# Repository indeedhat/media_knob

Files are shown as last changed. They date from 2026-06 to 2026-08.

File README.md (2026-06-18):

# Media Knob
A little HID device to control media and scrolling.

Tested on linux, macos and windows

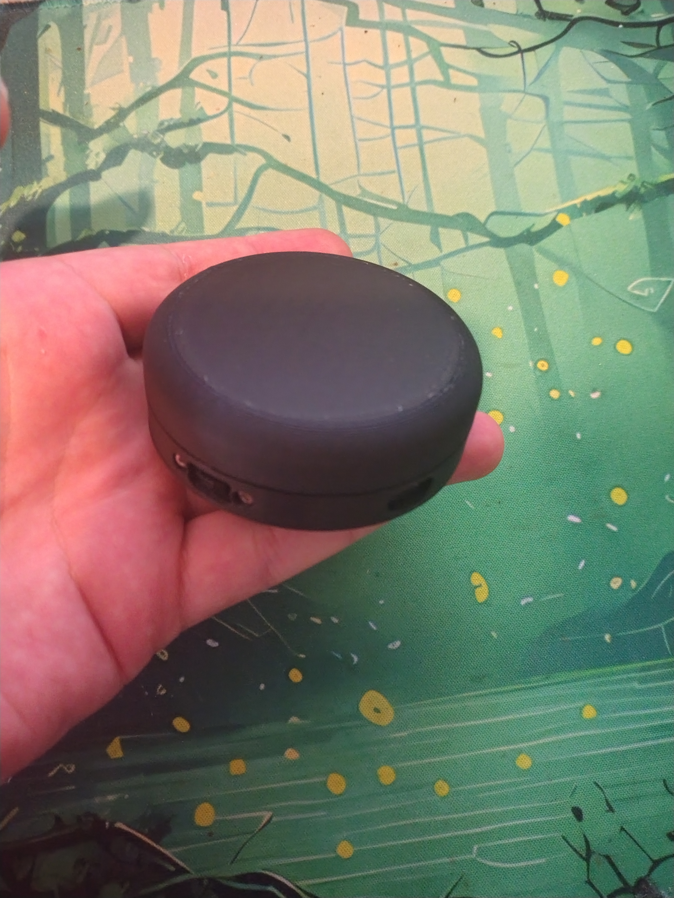
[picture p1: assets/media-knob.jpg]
media knob


## Build Guide
[Build Guide found heer](build-guide.md)

## Controls
The device has 3 inputs:
- Spin dial
- Side button (mode switch)
- Button in base under the foot opposite the USB port (Mod)

### Scroll mode

| Direction | Mod | Action |
| --- | --- | --- |
| Clockwise | No | Scroll Up |
| Counter Clockwise | No | Scroll Down |
| Clockwise | Yes | Zoom in |
| Counter Clockwise | Yes | Zoom out |

### Media Mode

| Direction | Mod | Action |
| --- | --- | --- |
| Clockwise | No | Volume Up |
| Counter Clockwise | No | Volume Down |
| Clockwise | Yes | Next track |
| Counter Clockwise | Yes | Previous track |
| N/A | Double Tap | Play/Pause |

## Bluetooth Operation
- The device shows up as "Knoblet".
- It will allow up to 5 devices to be paired but only one device to be connected at a time.
- pairing to a 6th device will remove the oldest pairing
- when pairing to a device that it already has a pairing for but the key has changed (for example if you remove the device from your pc and then re add it) connection will fail the first time and the pairing will be cleared for that device. The secrond time you try connect it will pair correctly. This is intended functionality to remove the need for a dedicated clear pairing button.

## OS Support
- Linux: works as intended out of the box
    - I do not know if all distros support high res scrolling but so far it has worked on all the distro's i have tried
- Windows: works as intended out of the box
- MacOS: does not natively support high res scrolling, I have had the best results using [Better Mouse](https://better-mouse.com/)

## Battery life
I have not been tracking this as well as I could have but I would estimate about 16 hours usage between charges with the 110mah battery I am using.
It is on my roadmap to implement some battery saving features but I haven't found time to prioritise them as of yet.

## Roadmap
### Software
- [x] scroll mode
    - [x] high res scrolling
    - [x] zoom
- [x] media media
    - [x] play/pause
    - [x] volume
    - [x] next/prev
- [x] mode switching (scroll/media)
- [ ] bluetooth
    - [x] Connect via bluetooth
    - [ ] low power mode
        - in progress
    - [x] properly report battery life
- [ ] usb
    - [x] get usb working alone
    - [ ] get usb working along side bluetooth

### Hardware
- [x] connect as5600 sensor
- [x] trigger a button when you press on the dial
- [x] mode switching button
- [x] sort out battery

### Cad
- [x] dial
- [x] bottom cover
- [x] main body (needs updating for buttons)

### Other
- [x] create build guide
    - needs updating
- [x] upload STL files for 3d printing

## Possible tasks
It might be nice to have a macro mode that lets you configure what the dial does in an application
running on the host device.

## Wiring
### as5600
- scl -> 011 - yellow
- sda -> 100 - green

### input
- mode -> 111 - blue
- mod  -> 010 - white

## Credits
The idea comes from [This Video](https://www.youtube.com/watch?v=FSy9G6bNuKA&t=287s) by
[Engineer Bo](https://www.youtube.com/@engineerbo) with some extra features of my own.  
Without that video a would never have had the idea to create a project like this on my own and
wouldn't even know that High res scrolling was a thing
There is absolutely no doubt in my mind that his version is significantly higher quality and more refined
than this project, this is more aimed for people that like to build things themselves.

The project is built on top of [Zephyr Project](https://www.zephyrproject.org/).

I spent a good amount of time reading through the bluetooth logic from [ZMK](https://zmk.dev/) to
get my bluetooth working, I don't recall directly copying any of their code but its likely to be
pretty damn similar in a lot of ways.

[Claude.ai](https://claude.ai) was my Clanker of choice for troubleshooting and helping with research
but was not used for code generation. It was of questionable usefulness throughout the project and
I am sceptical of if it actually saved me any time but I did make use of it to some degree and I
think that its important to recognise its usage.

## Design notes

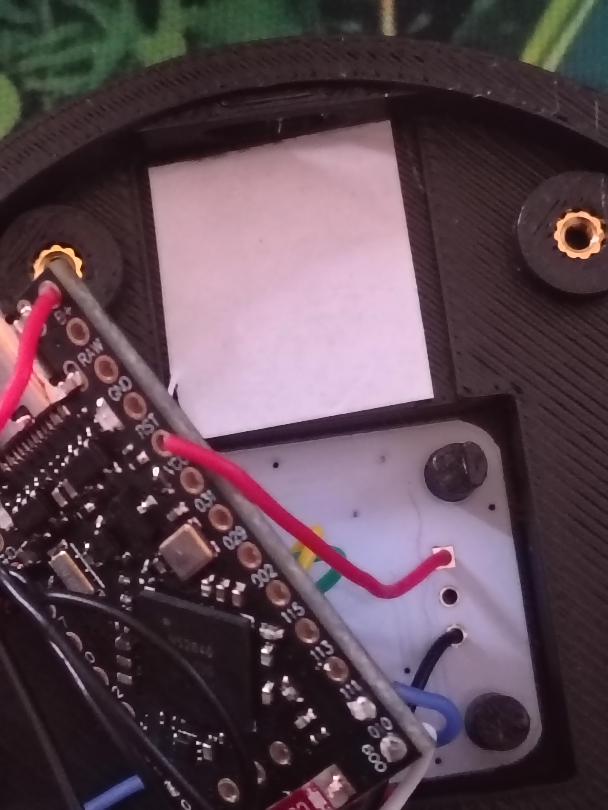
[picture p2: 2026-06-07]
assets/pro-micro-tape.jpg

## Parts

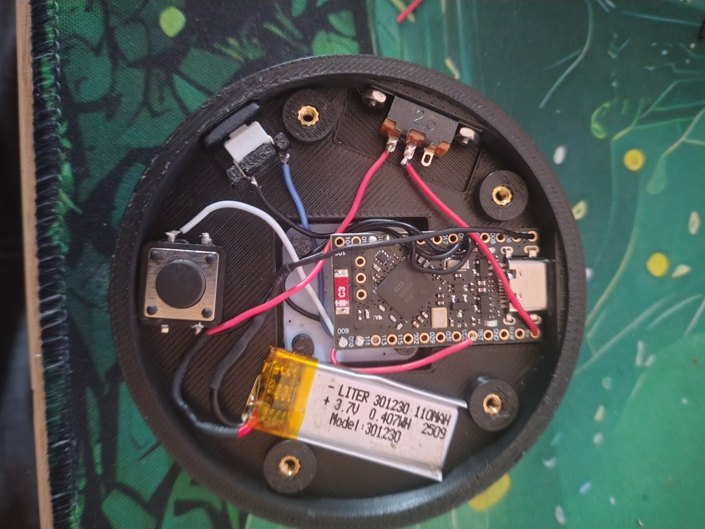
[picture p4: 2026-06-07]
assets/final-parts-in.jpg

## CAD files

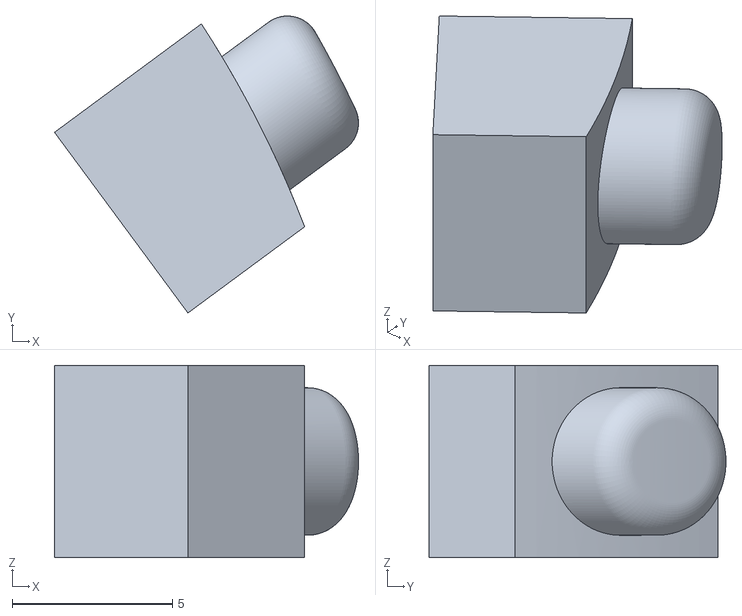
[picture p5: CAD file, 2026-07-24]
cad/side-button-2.stl
9.48 x 9.26 x 6.00

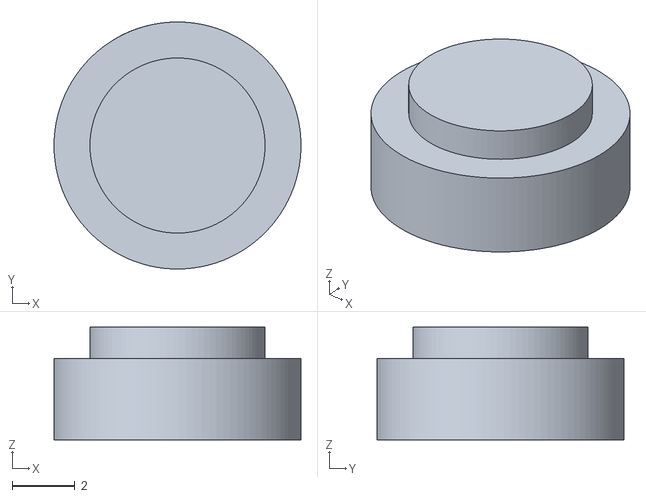
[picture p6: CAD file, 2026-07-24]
cad/mod-button.stl
7.90 x 7.90 x 3.60

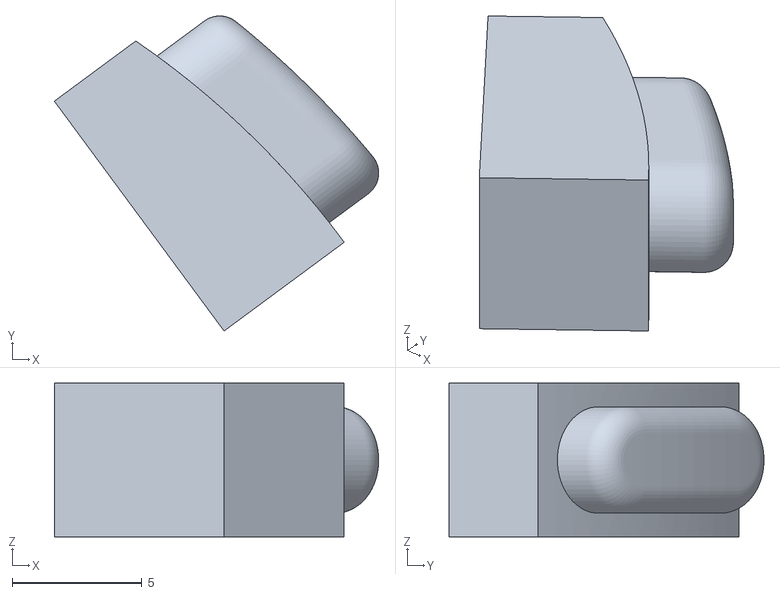
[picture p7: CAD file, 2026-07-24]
cad/side-button-1.stl
12.5 x 12.1 x 5.92

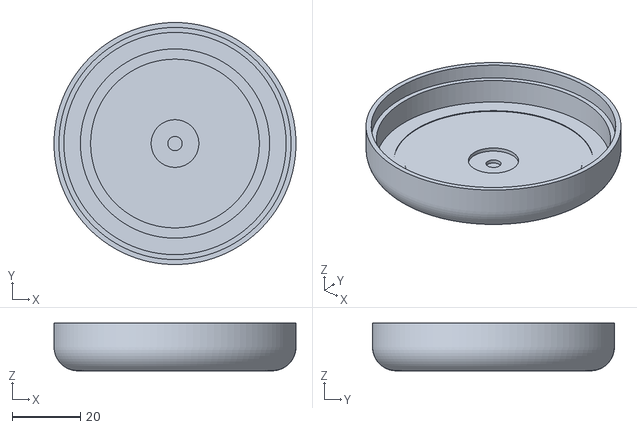
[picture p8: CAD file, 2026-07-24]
cad/dial.stl
71.0 x 71.0 x 14.0

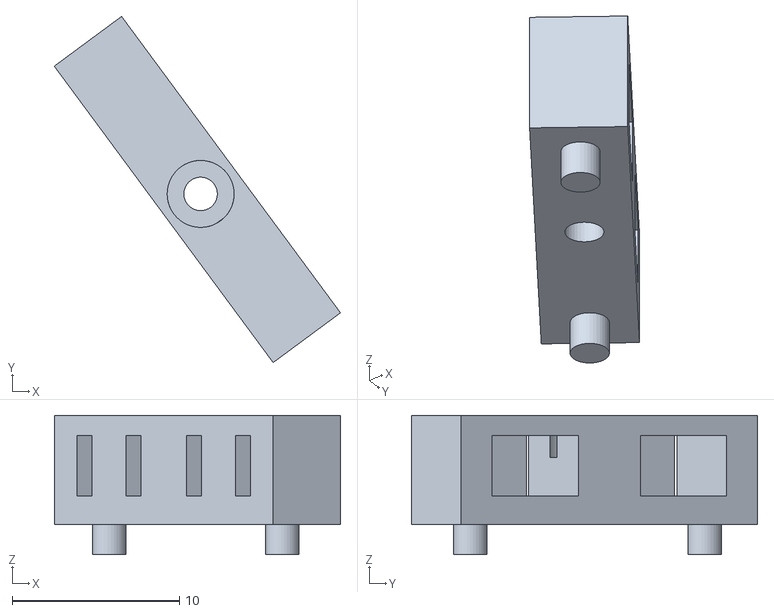
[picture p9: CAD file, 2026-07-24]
cad/side-button-cage.stl
17.1 x 20.7 x 8.30

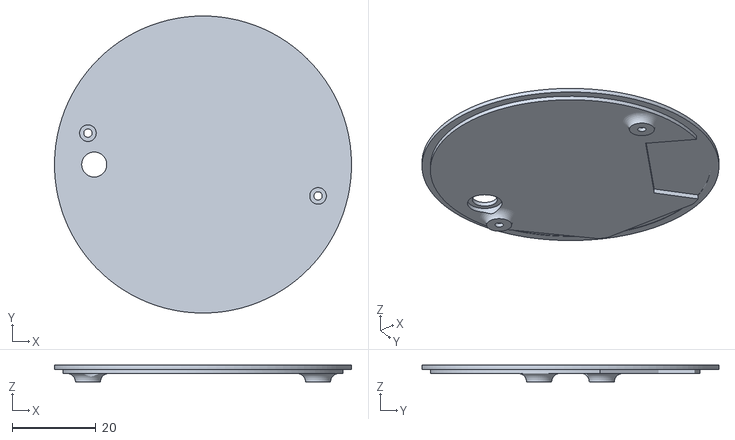
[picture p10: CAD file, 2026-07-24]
cad/bottom-cover.stl
71.0 x 71.0 x 4.00

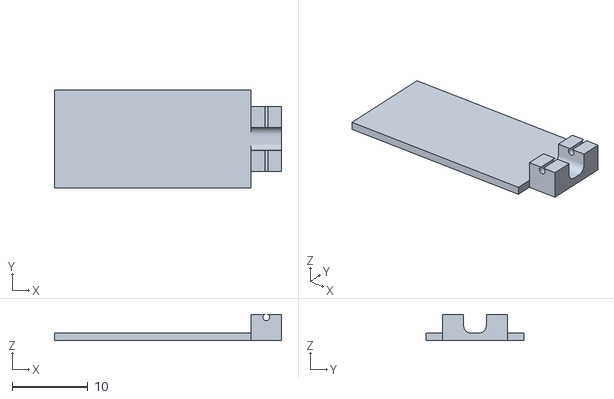
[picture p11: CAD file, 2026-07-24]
cad/controller-sledge.stl
30.0 x 13.0 x 3.50

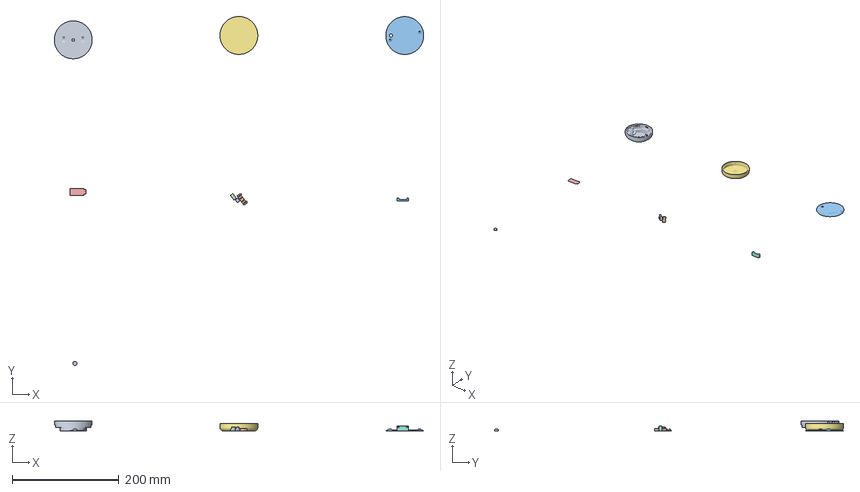
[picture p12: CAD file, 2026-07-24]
cad/knoblet-v2.3mf
692.1 x 653.8 x 18.9 mm
body.stl
side-button-cage.stl
bottom-cover.stl
side-button-1.stl
controller-sledge.stl
side-button-2.stl
dial.stl
usb-bracket.stl
mod-button.stl

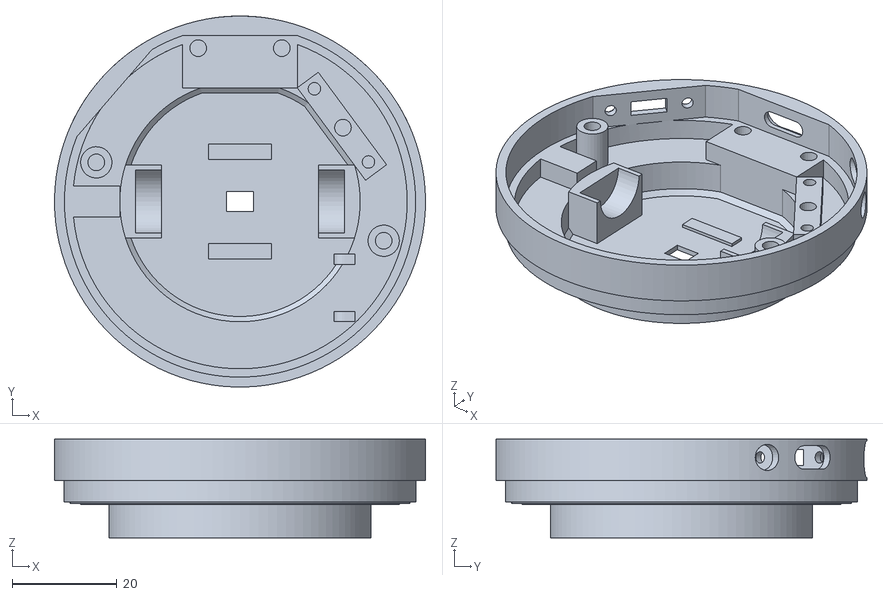
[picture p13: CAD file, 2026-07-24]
cad/body.stl
71.0 x 71.0 x 18.9

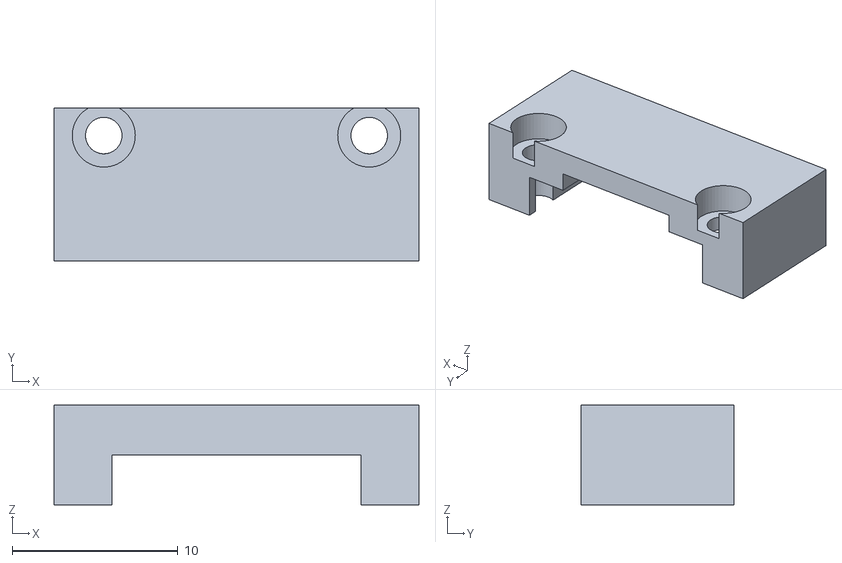
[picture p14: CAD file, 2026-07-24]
cad/usb-bracket.stl
22.0 x 9.20 x 6.00

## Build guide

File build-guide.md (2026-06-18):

## Parts list

> [!NOTE]
> This build guide is a little out of date, the base has been rearranged and there is now a button in the bottom cover
> for the mod button, It should still be close enough to manage the build but i will update this soon with new pictures
> and updated instructions

### Electrical
- 1x [Pro micro nrf52840 micro controller](https://www.aliexpress.com/w/wholesale-Nrf52840-Pro-Micro.html?spm=a2g0o.detail.search.0)
- 1x [as5600 magnetic encoder (white dev board)](https://www.aliexpress.com/w/wholesale-as5600.html?spm=a2g0o.productlist.search.0)
- 1x [301230 lipo battery](https://www.aliexpress.com/w/wholesale-301230.html?spm=a2g0o.productlist.search.0)
- 1x 6x6x4.3 push button
- 1x 12x12x5 patch push button
- 1x SS12D10 2 position toggle switch

### Hardware
- 4x m2x4x3.2 heat set inserts
- 6x m2x4 bolts
- 2x m2 nuts

### Printed Parts
- 1x [Dial Base](cad/base.stl)
- 1x [Base Cover](cad/bottom-cover.stl)
- 1x [Dial Top](cad/dial.stl)
- 1x [Mode Switch Button](cad/mode-button.stl)

### Other
- 1x [65mm od x 50mm x 7mm bearing ](https://www.aliexpress.com/item/1005011831553272.html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{%22order%22%3A%2214%22%2C%22eval%22%3A%221%22%2C%22fromPage%22%3A%22search%22}&pdp_npi=6%40dis!GBP!13.41!6.71!!!118.46!59.23!%40211b655217808439447296990e0848!12000056729960207!sea!UK!2482384161!X!1!0!n_tag%3A-29919%3Bd%3Acda67a48%3Bm03_new_user%3A-29895&curPageLogUid=0vgzU3UKqwhK&utparam-url=scene%3Asearch|query_from%3A|x_object_id%3A1005011831553272|_p_origin_prod%3A)
- 5x rubber feet (whatever size you want)
- thing gage wire
- heat shrink (optional but recommended)
- double sided tape

### Tools
- Soldering Iron
- driver for m2 bolts
- wire cutters
- wire strippers
- 3d printer

## Build instructions
1) Insert the bearing into the dial top. This should fit snugly without any need for adhesive.
2) Insert the magnet provided with your as5600 into the center cavity of the dial top. This should fit snugly but a little adhesive is probably a good idea.
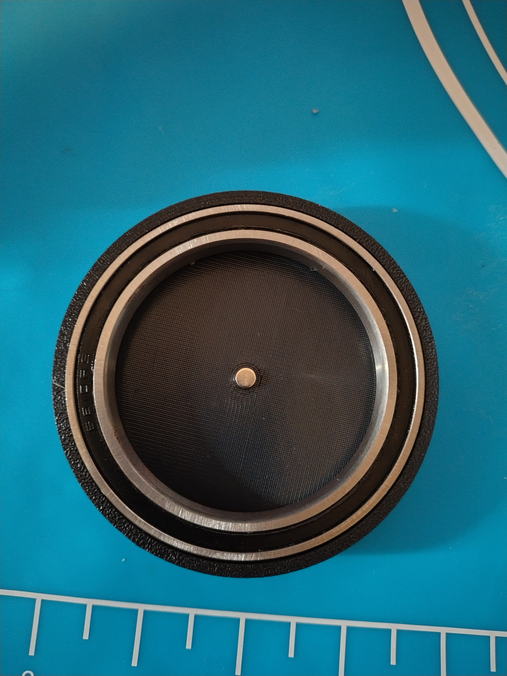
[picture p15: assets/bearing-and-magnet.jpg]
bearing and magnet


3) Use a soldering iron to insert the m2 heated inserts into their holes
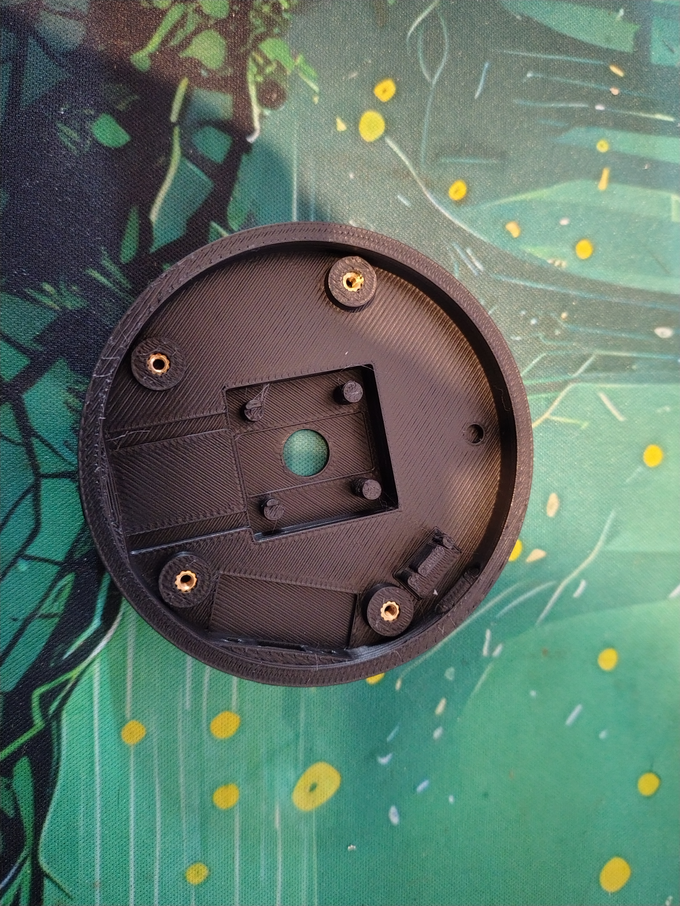
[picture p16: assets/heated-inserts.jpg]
heated inserts


4) solder wires to the GND, VCC, SCL and SDA pins of the as5600 with the wires trailing out through the back
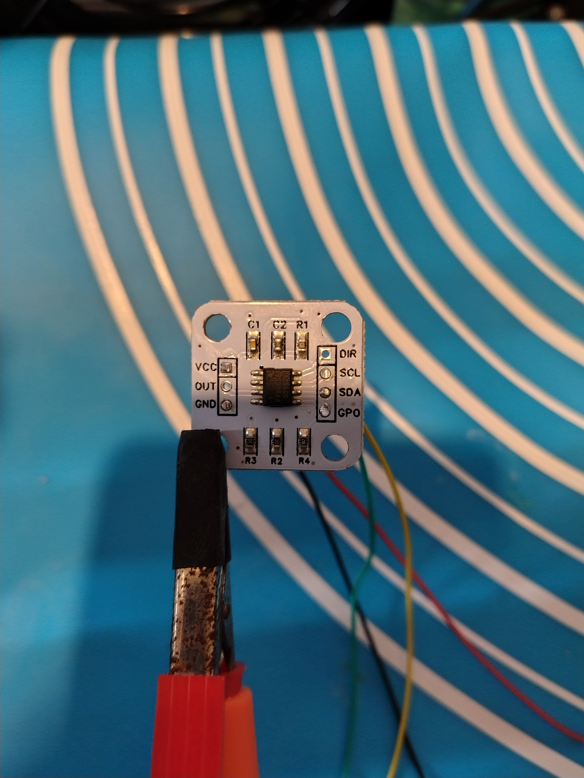
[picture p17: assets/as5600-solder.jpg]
as5600 wires


5) Insert the as5600 into its recess. All of my boards have the sensor slightly offset and the print has been adjusted to account for this, you need the 4 hole side aligned with the power switch cutout to properly align the sensor.
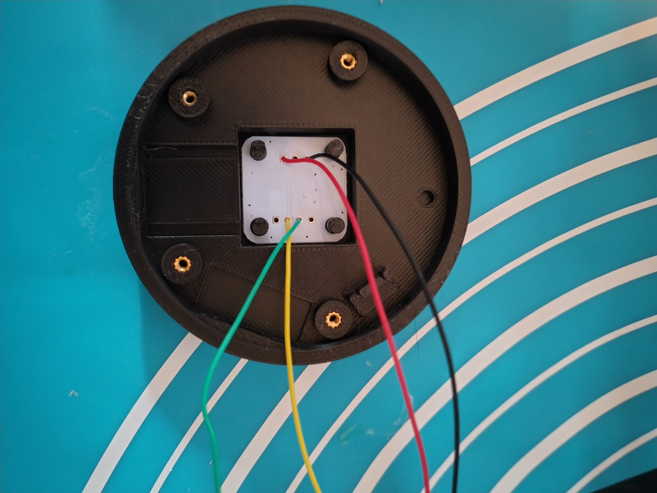
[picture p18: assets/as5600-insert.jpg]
as5600 insert


6) Insert the Mode switch button into its cutout and secure with the 6x6x4.3 push button.
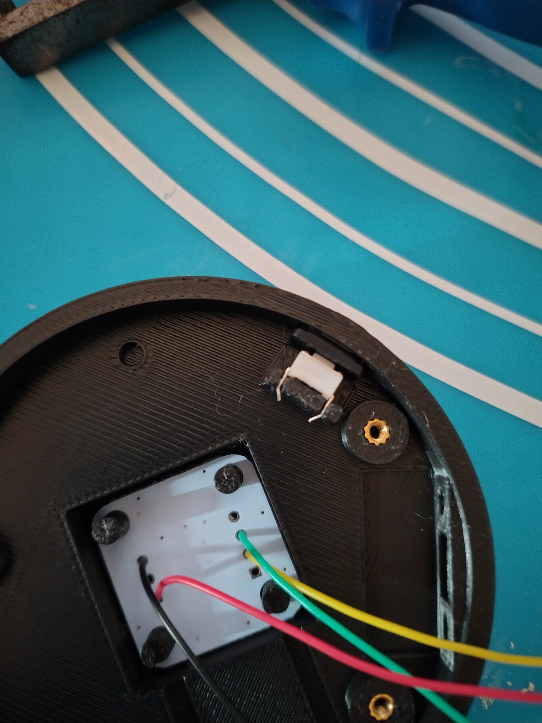
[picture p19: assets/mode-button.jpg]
mode button


7) Solder 2 wires to the power button then screw it into place. You can solder the wires after insertion but doing them first is much simpler
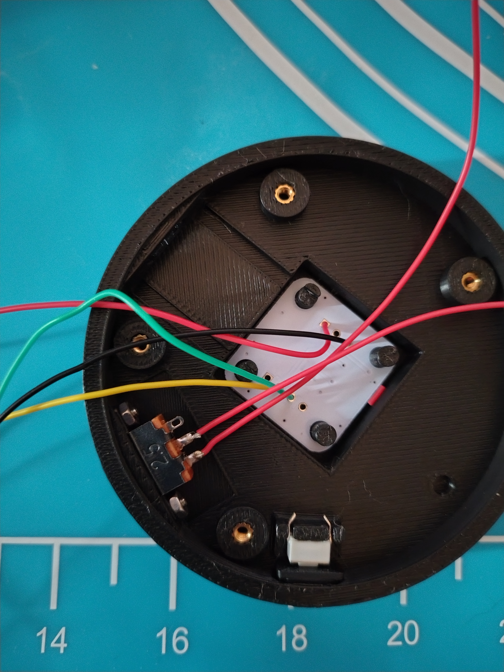
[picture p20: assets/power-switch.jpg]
power switch


8) Solder a data and ground wire to the mode switch button
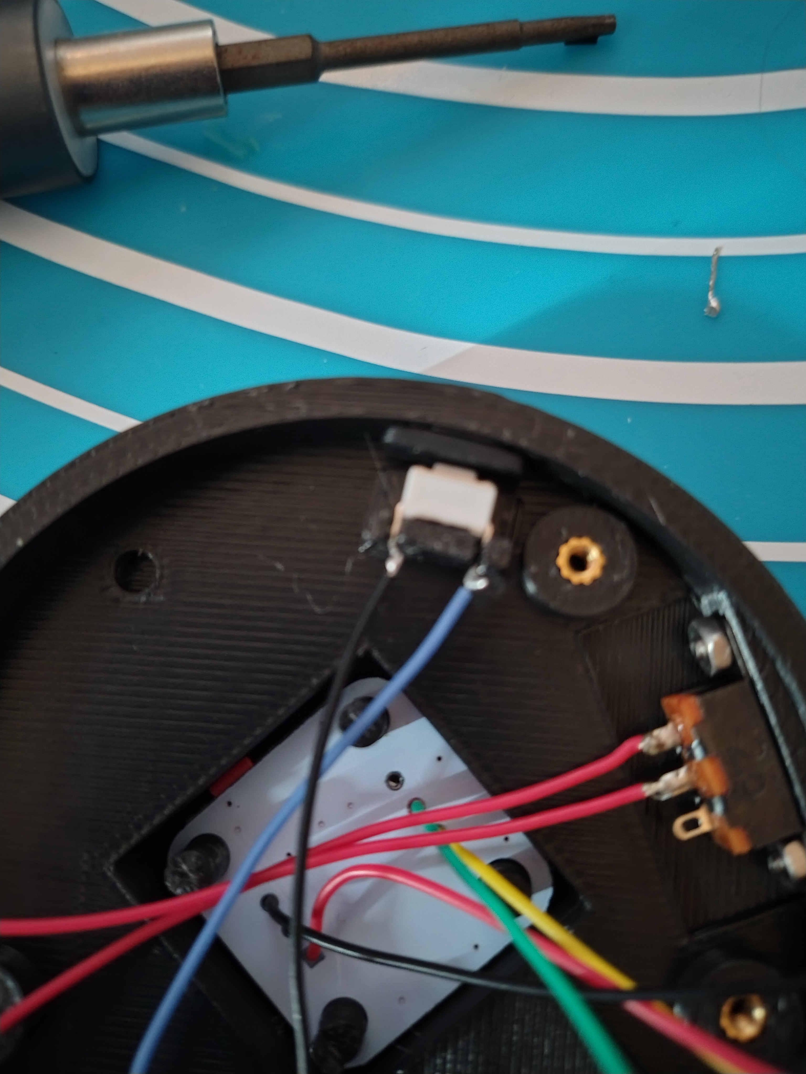
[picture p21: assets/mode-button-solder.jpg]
mode button solder


9) Solder a ground and data wire to the 12x12x5 push button and use a small amount of double sided tape to secure it in place.  
    __Note: here that in the image I have soldered the wires in the wrong location, they should be diagonal from each other.__
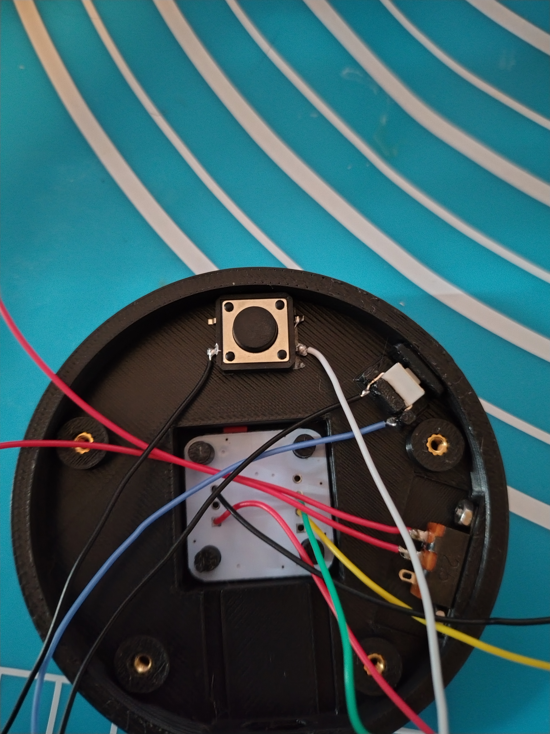
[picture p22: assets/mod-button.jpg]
mod button


10) Cut all your wires to a more reasonable length and solder everything to the micro controller.

| component | wire | pin |
| --- | --- | --- |
| as5600 | GND (black) | GND |
| as5600 | VCC (red) | VCC |
| as5600 | SCL (yellow) | 011 |
| as5600 | SDA (green) | 100 |
| Mode Sw | black | GND |
| Mode Sw | blue | 111 |
| Mod Sw | black | GND |
| Mod Sw | white | 010 |
| Power Sw | red | B+ |
| N/A | black | B- |

11) Stick the micro controller in place with some double sided tape.  
    __Note: the cheap controllers don't all have the usb port at the same height relative to the board. I have setup the model to account for the most offset board i have and so you may need to pad the bottom of the board to make it line up propperly__
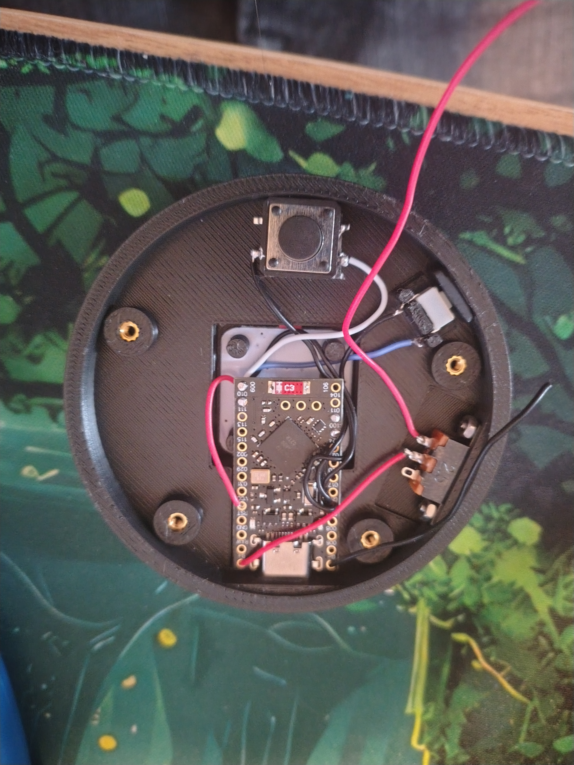
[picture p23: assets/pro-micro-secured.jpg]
pro micro secured


12) Wire up the battery to the remaining power switch wire and black wire coming out of B-. I recommend using either some heat shrink if you have it or electrical tape to wrap the wires and prevent shorts.
13) Stick the battery in place with some double sided tape.
parts in place

14) push the dial top into place over its peg. This should fit snugly with no need  for adhesive.

15) flash the controller:
    - Connect the pro micro to a computer via usb
    - quickly short the rst pin to gnd twice
    - the red light should slowly pulse and an external storage device will show up on your computer
    - copy the latest uf2 file from the releases page to your controller.
    - once coppied the device will automatically eject from your computer and restart.

16) screw the base plate into place.  
    Don't put too much screw pressure on the two bolts either side of the mod button or it will stay permanently pressed.

17) turn on the power switch and connect the device to start using it.

## Note on charging
To actually charge the device the power switch needs to be in the on position or there will be no connection to the battery.

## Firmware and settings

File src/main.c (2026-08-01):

#include <zephyr/sys/printk.h>
#include <zephyr/device.h>
#include <zephyr/drivers/regulator.h>
#include <zephyr/input/input.h>
#include <zephyr/settings/settings.h>
#include <zephyr/drivers/gpio.h>
#include <zephyr/kernel.h>

#include "main.h"
#include "hid.h"
#include "bt.h"
#include "as5600.h"
#include "battery.h"
#include "zephyr/init.h"
#include "zephyr/logging/log.h"


static void scroll_action(int16_t angle);
static void media_action(int16_t angle);
#if defined CONFIG_KNOBLET_ENABLE_MACRO_MODE
static void macro_action(int8_t button_idx, int8_t button_state, int16_t angle);
#endif
static void button_input_cb(struct input_event *evt, void *user_data);
static void trigger_media_event(uint16_t media_event);
static void init_settings();
static void submit_report(const char *trigger_name, const uint16_t size, const uint8_t *const report);


int current_mode = MODE_SCROLL;
int mod_btn_pressed = 0;

int64_t last_seek_time = 0;
int64_t last_mod_up_time = 0;


devices device_state = {
	.as5600 = DEVICE_DT_GET_ANY(ams_as5600),
};

static const struct gpio_dt_spec vcc_enable = {
    .port = DEVICE_DT_GET(DT_NODELABEL(gpio0)),
    .pin = 13,
    .dt_flags = GPIO_ACTIVE_HIGH,
};


LOG_MODULE_REGISTER(main, LOG_LEVEL_DBG);
INPUT_CALLBACK_DEFINE(NULL, button_input_cb, NULL);


SYS_INIT(bt_init, APPLICATION, 1);


int main(void)
{
	int err;

	gpio_pin_configure_dt(&vcc_enable, GPIO_OUTPUT_ACTIVE);

#if defined CONFIG_KNOBLET_SAVE_MODE_STATE
	init_settings();
#endif

	err = init_battery_level();
	if (err) {
		LOG_ERR("Failed to init battery report loop");
	}

	err = as5600_init(device_state.as5600);
	if (err != 0) {
		return err;
	}

	while (true) {
		if (as5600_jitter_compensation_enabled()) {
			k_msleep(AS5600_JITTER_DELAY_MS);
		} else {
			k_msleep(current_mode == MODE_SCROLL ? SCROLL_POLL_DELAY : MEDIA_POLL_DELAY);
		}

		int16_t angle = as5600_read(device_state.as5600);

		switch (current_mode) {
		case MODE_SCROLL:
			scroll_action(angle);
			break;
		case MODE_MEDIA:
			media_action(angle);
			break;
#if defined CONFIG_KNOBLET_ENABLE_MACRO_MODE
		case MODE_MACRO:
			macro_action(0, 0, angle);
			break;
#endif
		};
	}

	return 0;
}


static void init_settings()
{
	int size = settings_load_one(SETTINGS_MODE, &current_mode, sizeof(current_mode));
	current_mode %= MODE_COUNT;

	if (size < 0) {
		LOG_ERR("failed to load mode from settings");
	}
}


/**
 * @brief scroll_action handles sending an angle event to the host when in scroll mode
 *
 * @param[in] angle the angle of change
 */
static void scroll_action(int16_t angle)
{
	if (angle == 0) {
		return;
	}

	uint8_t report[MOUSE_REPORT_SIZE] = {0};
	report[MOUSE_REPORT_IDX] = MOUSE_REPORT_ID;
	report[MOUSE_ANGLE_IDX] = angle;

	submit_report("hid scroll", MOUSE_REPORT_SIZE, report);
}


/**
 * @brief media_action handles sending an angle event to the host when in media mode
 *
 * @param[in] angle the angle of change
 */
static void media_action(int16_t angle)
{
	uint8_t report[MEDIA_REPORT_SIZE];
	report[MEDIA_REPORT_IDX] = MEDIA_REPORT_ID;
	
	if (angle == 0) {
		return;
	}

	// After we skip the track we want to debounce for a short period so we
	// don't accidentally skip multiple tracks or change the volume as we
	// release the press.
	// The debounce time is purely set based on when the skip happens.
	int64_t now = k_uptime_get();
	if (now < last_seek_time + MEDIA_DEBOUNCE_TIME) {
		if (mod_btn_pressed) {
			last_seek_time = now;
		}
		return;
	}

	if (mod_btn_pressed) {
		last_seek_time = now;

		trigger_media_event(angle > 0
			? HID_MEDIA_SCAN_NEXT
			: HID_MEDIA_SCAN_PREV
		);
		return;
	}

	trigger_media_event(angle > 0
		? HID_MEDIA_VOL_UP
		: HID_MEDIA_VOL_DONW
	);
}


#if defined CONFIG_KNOBLET_ENABLE_MACRO_MODE
/**
 * @brief macro_action handles sending all input to the desktop application when in macro mode
 *
 * @param[in] button_idx the current button being pressed/released (0 = no button)
 * @param[in] button_state the current state of the button in question
 * @param[in] angle the angle of change
 */
static void macro_action(int8_t button_idx, int8_t button_state, int16_t angle)
{
	if (angle == 0 && button_idx == 0) {
		return;
	}

	uint8_t report[MACRO_REPORT_SIZE];
	report[MACRO_REPORT_IDX] = MACRO_REPORT_ID;
	report[MACRO_KEY_IDX] = button_idx;
	report[MACRO_KEY_STATE_IDX] = button_state;
	report[MACRO_ANGLE_HIGH_IDX] = angle >> 8;
	report[MACRO_ANGLE_LOW_IDX] = angle & 0xFF;


	LOG_INF("macro angle %d", angle);
	submit_report("macro", MACRO_REPORT_SIZE, report);
}
#endif


/**
 * @brief button_input_cb hadles button presses when the evnt is sent from the zephyr
 *        input subsystem
 *
 * @param[in] evt the input event
 * @param[in] user_data the user data for the event
 */
static void button_input_cb(struct input_event *evt, void *user_data)
{
	LOG_INF("button pressed %d", evt->code);

	if (evt->sync == 0) {
		return;
	}

	if (evt->code == BTN_MODE_CODE) {
		if (evt->value != 0) {
			return;
		}

		current_mode = (current_mode + 1) % MODE_COUNT;

	#if defined CONFIG_KNOBLET_SAVE_MODE_STATE
		int err = settings_save_one(SETTINGS_MODE, &current_mode, sizeof(current_mode));
		if (err != 0) {
			LOG_ERR("Failed to save mode to settings");
		}
	#endif

		LOG_INF("Set mode to %s", current_mode == MODE_SCROLL ? "scroll" : "media");
		return;
	}

	if (evt->code != BTN_MOD_CODE && evt->code != BTN_MOD2_CODE) {
		return;
	}

	mod_btn_pressed = evt->value;
	switch (current_mode) {
	case MODE_MEDIA:
		if (evt->value) {
			return;
		}

		int64_t now = k_uptime_get();
		if (last_mod_up_time + MEDIA_DOUBLE_TAP_INTERVAL > now) {
			last_mod_up_time = 0;

			trigger_media_event(HID_MEDIA_PLAY_PAUSE);
			return;
		}

		last_mod_up_time = now;
		break;

	case MODE_SCROLL:
		uint8_t report[KEEB_REPORT_SIZE] = {0};
		report[KEEB_REPORT_IDX] = KEEB_REPORT_ID;
		report[KEEB_MODIFIER_IDX] = evt->value
			? HID_KBD_MODIFIER_LEFT_CTRL
			: HID_KBD_MODIFIER_NONE;

		submit_report("hid keeyboard",KEEB_REPORT_SIZE, report);
		break;

#if defined CONFIG_KNOBLET_ENABLE_MACRO_MODE
	case MODE_MACRO:
		macro_action(evt->code, evt->value, 0);
		break;
#endif
	}
}


/**
 * @brief submit_report submits a HID report to the host via the bluetooth subsystem
 *
 * @param[in] trigger_name display name for the log
 * @param[in] size the report size
 * @param[in] report the report data
 */
static void submit_report(
	const char *trigger_name,
	const uint16_t size,
	const uint8_t *const report
) {
	if (!bt_connected()) {
		return;
	}

	int err = bt_submit_report(size, report);
	if (err) {
		LOG_ERR("failed to send %s event: %d", trigger_name, err);
		return;
	}

	LOG_DBG("%s event sent", trigger_name);
}


/**
 * @brief trigger_media_event builds and sends a HID media event to the bluetooth
*         subsystem for both the keydown and keyup states
 *
 * @param[in] media_event the media event type to be triggered
 */
static void trigger_media_event(uint16_t media_event)
{
	uint8_t report[MEDIA_REPORT_SIZE] = {0};
	report[MEDIA_REPORT_IDX] = MEDIA_REPORT_ID;
	report[MEDIA_ACTION_LOW_IDX]  = media_event & 0xFF;
	report[MEDIA_ACTION_HIGH_IDX] = media_event >> 8;

	submit_report("media down", MEDIA_REPORT_SIZE, report);

	k_msleep(1);

	report[MEDIA_ACTION_LOW_IDX]  = 0;
	report[MEDIA_ACTION_HIGH_IDX] = 0;

	submit_report("media up", MEDIA_REPORT_SIZE, report);
}

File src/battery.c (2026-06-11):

#include <zephyr/kernel.h>
#include <zephyr/sys/util.h>
#include <zephyr/bluetooth/services/bas.h>
#include <zephyr/device.h>
#include <zephyr/drivers/adc.h>

#include "battery.h"


static void update_cb(struct k_work *work);
static int read_battery_percent();


static const struct adc_dt_spec adc_channel = ADC_DT_SPEC_GET(DT_PATH(zephyr_user));
static K_WORK_DELAYABLE_DEFINE(battery_update_work, update_cb);


int init_battery_level()
{
	int err = k_work_schedule(&battery_update_work, K_NO_WAIT);
	if (err <= 1) {
		return 0;
	}

	return err;
};


static void update_cb(struct k_work *work)
{
	int level = read_battery_percent();
	if (level >= 0) {
		bt_bas_set_battery_level(level);
	}

	k_work_schedule(&battery_update_work, K_SECONDS(BAS_POLL_INTERVAL_S));
}


static int read_battery_percent()
{
	int16_t sample;
	int32_t mv;

	struct adc_sequence seq = {
		.buffer = &sample,
		.buffer_size = sizeof(sample),
	};

	adc_sequence_init_dt(&adc_channel, &seq);
	adc_channel_setup_dt(&adc_channel);
	adc_read(adc_channel.dev, &seq);

	mv = sample;
	adc_raw_to_millivolts(adc_ref_internal(adc_channel.dev), ADC_GAIN_1_6, 12, &mv);
	mv *= BAS_VOLTAGE_DIVIDER;

	if (mv > BAS_USB_CONNECTED_MV) {
		return -1;
	}

	mv = CLAMP(mv, BAS_CLAMP_MIN, BAS_CLAMP_MAX);
	return (mv - BAS_CLAMP_MIN) * 100 / (BAS_CLAMP_MAX - BAS_CLAMP_MIN);
}

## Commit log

2026-05-23 feat: got sensor being read
2026-05-25 feat: implemented - mode switching - modifier key - media: prev/next - media: vol+/- - scroll: zoom
2026-05-25 fix: removed debug code, fixed button codes
    [main.c]
2026-05-25 fix: media device is now working but events are sketchy don't always send
2026-05-25 feat: implemented play/pause
    this is currently not working, the event shows up in libinput but
    spotify ignores it
    [main.c]
2026-06-06 refactor: extend media debounce to volume control after skip
    [main.c]
2026-06-07 docs: added build guide
    [base.stl, bottom-cover.stl, dial.stl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]
2026-06-07 feat: correctly report battery charge state + some power management tweaks
    [battery.c, main.c]
2026-06-09 refactor: general improvements - smoother scroll - jitter compensation - re advertise on dc - general code cleanup
    [battery.c]
2026-06-17 refactor: updated jitter compensation to make it less "sticky"
    [main.c]
2026-06-18 feat: updated 3d models - added bearing race for smoother mechanical movement - rearranged switches in the base for better mode switching ergonomics - moved sensor slightly closer to magnet to reduce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
    [base.stl, bottom-cover-button.stl, bottom-cover.stl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]
2026-07-18 feat: added a second mod button
    also cleaned up same code
2026-07-18 feat: added stl files for knoblet v2
    [base.stl, body.stl, bottom-cover-button.stl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]
2026-07-24 refactor: updated button config for final wirring
    also updated most models
    [body.stl, bottom-cover.stl, controller-sledge.stl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]
